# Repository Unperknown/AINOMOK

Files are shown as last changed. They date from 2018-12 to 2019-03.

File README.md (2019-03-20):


HitCount (http://hits.dwyl.io/Unperknown/AINOMOK)

# AINOMOK

📜
**[View Entire Documentation](https://github.com/Unperknown/AINOMOK/blob/master/doc/Plan%20Document.pdf)**

2016년에 성행한 알파고와 이세돌과의 경기 모습에서 영감를 받아 오목을 두는 기계와 사람이 오목 게임을 할 수 있도록 한다. 기계는 인공지능이 내장된 데스크탑과 통신하여 실제 고수와 같이 게임하는 것 같이 구현하였다.

구현을 위한 영상 처리 기술과 인공 지능은 Python 라이브러리 OpenCV와 Tensorflow를 사용해 작성하였으며 기계 제어와 통신 프로세스는 Arduino의 GRBL쉴드를 사용하여 3D Printer와 흡사하게 작동 할 수 있도록 C언어로 작성하였다. 물리적 설계는 3D 모델링으로 Fusion 360을 사용하였다.

## 📊Purpose

우리 학교 특성 상 소프트웨어 개발에 집중되어 있어 실제 기계에서 소프트웨어가 어떻게 활용되는지 알 수 없었는데 이번에 프로젝트를 진행하면서 알고 싶어서 로봇에 인공지능을 넣을 수 있도록 하였다.

그리고 조립한 기계 산출물이 전시회 이후에 사용되지 않고 버려지는 문제점에서 벗어나기 위해 보다 더 실용도가 높은 산출물을 개발하고 싶어서 최대한 흥미로운 아이디어를 접목하고 싶었다.

## ☑️Features
- 로봇은 오목판의 영상 처리를 통해 현재 상태를 분석하여
둘 수 있는 수 중 최적의 수를 전달한다.
- 구성품의 LCD 패널에서 출력되는 정보를 통해 현재 게임 스테이지의 상태를
알 수 있다.

## 🔘Entire Design
### Estimated Outputs
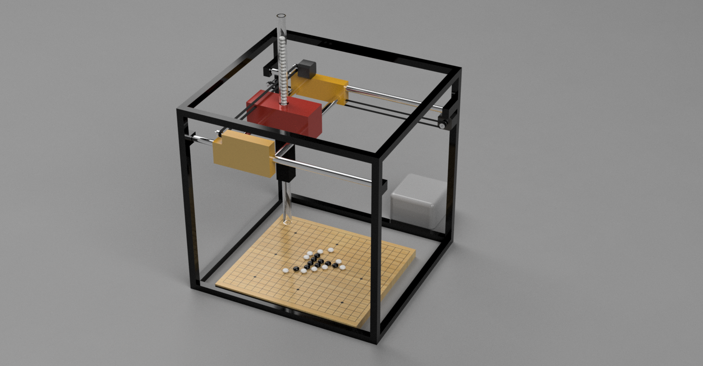
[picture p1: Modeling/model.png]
예상 완성본 모델링 사진


### System Design

## 👪Contributors

### Project Group
- [🔗Unperknown](https://github.com/Unperknown) : Image Processing, AI Development
- [🔗asphalt-alpha](https://github.com/asphalt-alpha) : Assembling Robot, 3D Modeling
- [🔗ohseyoung123](https://github.com/ohseyoung123) : Arduino Programming

### Others
- [🔗Las-Wonho](https://github.com/Las-Wonho) : Correction of document(README.md)
- [🔗cdb0915](https://github.com/cdb0915) : Arduino Programming Assistant

## 🔑Stack
  
- Python
  - Tensorflow(for C: Partically uses Ubuntu OS)
  - OpenCV

- Arduino

- 3D Printing & Modeling

## 🕤Daily Progress
### Day 1(12/27) - 계획서 수정 및 개발 과정 설계

##### 1. 계획서 버전 수정 및 브로슈어 추가

doc 디렉토리의 계획서를 10/24(Ver.1)에서 12/26(Ver.2)로 Commit하였다. 그리고 계획 수립 과정 중 판넬 구성을 하기로 결정함에 따라 브로슈어 원본을 추가하였다.

##### 2. 시스템 설계
**시스템 설계의 도식은 나중에 업데이트될 예정이다.**

구현은 오목 게임의 상태를 저장하고 제어하는 데스크탑과 물리적인 상태 저장과 출력을 담당하는 아두이노 간의 통신으로 이루어질 것이다. 데스크탑은 웹캠과 연결되어 웹캠에서 주어진 오목판의 이미지를 영상 처리하여 오목판을 저장하는 배열의 각 상태를 업데이트한다. 각 업데이트를 Round로 나누어 각 Round마다 데스크탑에 내장된 RL 모델이 컴퓨터가 둘 좌표를 판단하여 그 좌표를 아두이노에 전달한다.

아두이노는 전달한 좌표에 따라 모터를 제어하는 프로시저에 따라 바둑판의 상태에 알맞게 둔다. 아두이노의 LCD 패널에 게임이 진행 중인지, 끝났는지 표시한다. 그리고 버튼을 눌러 게임을 시작하는 신호나 중지하는 신호를 데스크탑으로 보낸다. 반대로 데스크탑은 오목 게임이 끝나는 Round에 게임이 끝났다는 신호를 아두이노로 보낸다.

### Day 2(12/28) - 개발 세팅 및 테스트 설계(단위 테스트)

##### 1. 부품 조달 확인

부품 조달이 지연되어 실전 테스팅은 시현 직전인 1월 5일부터 1월 7일까지 하기로 결정하였다. 부품이 오는 동안 프로세스의 구현과 RL 모델 훈련을 하는 것으로 결정하여 Day 3부터 본격적으로 개발하기로 하였다.

##### 2. 개발 환경 및 테스트

영상 처리: 테스트는 부품이 오지 않아 임시로 노트북의 웹캠으로 대신 테스트할 것이다. 이미지나 영상을 띄웠을 때 검은 돌과 하얀 돌이 어느 좌표에 있는지 CLI에 출력하는 것으로 단위 테스팅할 것이다.

RL 모델: 시간 내에 구현하지 못할 가능성을 방지하기 위해 시초에는 Python의 easyAI 라이브러리로 먼저 구현할 것이다. 그러고 나서 알맞게 리팩토링하여 Tensorflow 라이브러리로 재작성할 것이다.

3D 모델링: 로봇 하드웨어를 구성하는 부품의 구성을 모델링하여 저장소에 커밋하여 보관한다. 그러고 나서 출력하여 부품이 오는 즉시 조립을 시작할 것이다.

### Day 3 ~ Day 5(12/29, 1/2 ~ 1/3) - 개발 수행

##### 1. Unperknown - Image Processing

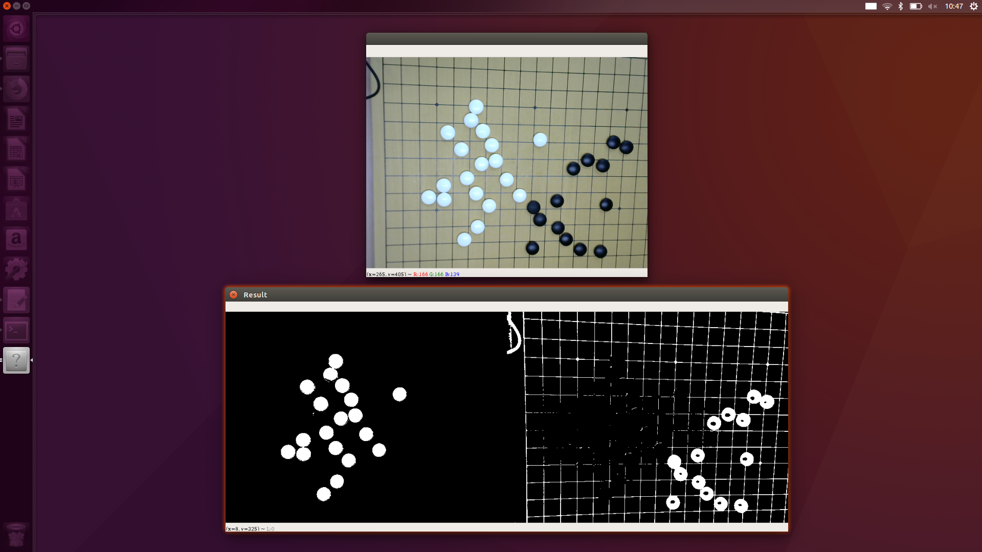
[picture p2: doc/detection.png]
영상 처리를 통한 바둑돌 감지 바둑돌 감지 사진


영상 처리를 통해 임시로 파란색을 감지하는 것을 성공하였다.(12/29) 그러고 나서 지속적인 색 감지 테스트를 통해 검은돌과 하얀돌의 위치를 화면으로 탐지할 수 있게 나는데 성공하였다.(1/3) 그러나 현재 하드웨어가 완성되지 않아 실제로 탐지되는지 테스트를 할 수 없는 상태이다. 색 탐지 값을 조정하는데 하드웨어에 설치된 스탠드의 빛의 밝기, 웹캠의 위치 등에 따라 상당히 달라질 수 있어 좌표의 색을 검출하여 오목판의 상태를 업데이트하는 프로세스는 AI 모델을 완성하고 게임 제어 프로그램을 구성한 후인 가장 마지막에 하기로 결정하였다.

현재 게임 제어 프로그램과 AI 모델은 src 디렉토리를 어떻게 구성할지에 대한 회의가 끝나고 나서 차근차근 커밋할 예정이다.

##### 2. ohseyoung123 - Arduino Programming

시리얼 통신을 C#로 작성하였다. 기본적인 틀을 숙지하고 나서 본격적으로 목적에 알맞게 구현할 것이다. 코드를 짜는데에 어려움을 겪어 검색과 친구들에게 물어봐가며 C++로 작성하려고 하였으나 지속적인 오류가 일어났다.(~1/2)방법을 찾던 중 선배의 도움을 받아 C#으로 작성할 수 있는 방법을 찾아 각 아두이노 핀으로 문자열을 출력하는 데에 성공하였다.(1/3)

##### 3. asphalt-alpha - 3D Modeling

부품을 모델링하였다. 저장소에 커밋하고 나머지 필요한 부품을 추가로 더 할 것이다.

### Day 6 ~ Day 8(1/4 ~ 1/6) - 개발 수행 및 테스트

##### 1. cdb0915 - Assistance of Arduino Programming

시리얼 통신을 구현을 검증하는 중에 ohseyoung123과의 협의를 거쳐 기술 한계 상 Python으로 재작성하자고 결정하였다.(1/4) 그래서 ohseyoung123이 작성한 소스 파일을 리뷰하고 현재 오목 제어 프로그램과 시리얼 통신 프로그램을 합치는 작업을 진행하고 있다.

##### 2. Unperknown - AI Development and Omok Program

하드웨어 안의 오목판의 상태를 담은 데이터를 가져와 현재 Round의 승리 여부를 확인하고 턴을 돌리는 제어 프로그램을 작성하였다.(12/28) 그 제어 프로그램에서 영상 처리를 통해 플레이어가 둔 돌의 좌표를 가져오는 메서드와 AI 모델을 실행하여 좌표를 가져오는 메서드는 현재 작업 중이다. 현재 모델이 훈련이 아직 되지 않았고 생겨난 버그를 수정하고 있다. (1/2 ~) 저번에 언급한 대로 내일(1/6)에 영상 처리를 통해 좌표를 불러오는 메서드를 실제 하드웨어에 연결해 테스트할 예정이다. 그러면서 그 메서드 소스 파일을 커밋할 것이다.

##### 3. asphalt-alpha - Assembling Robot

현재 설계도에 계획한 도면대로 대부분의 물리적 구현을 마치고 있다.(1/4 ~) 그러나 세세한 작업을 하면서 웹캠까지 다 설치하는데 시간이 걸려 최종적인 테스트는 내일(1/7) 하기로 하였다. 

### Day 8 ~ Day 9(1/7 ~ 1/8) - 프로젝트 일시 중단

하드웨어와 프로그램 간의 네트워크 구현이 원활하게 이루어지지 않았고 영상 처리 기술을 구현하는데 시간이 매우 촉박하였다. 그래서 프로토타입만 전시하기로 결정하였다.

### Day 10(5/14? ~ ) - 프로젝트 재개

각 팀원의 스케줄 문제로 2분기 방과후 프로그램에 프로젝트 반을 따로 구성하여 그 시간 동안 완성하기로 결정하였다. 정확한 재개 날짜는 아직 정해지지 않았다.

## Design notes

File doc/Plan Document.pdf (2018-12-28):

## 2018년도 GSM 프로젝트 페스티벌

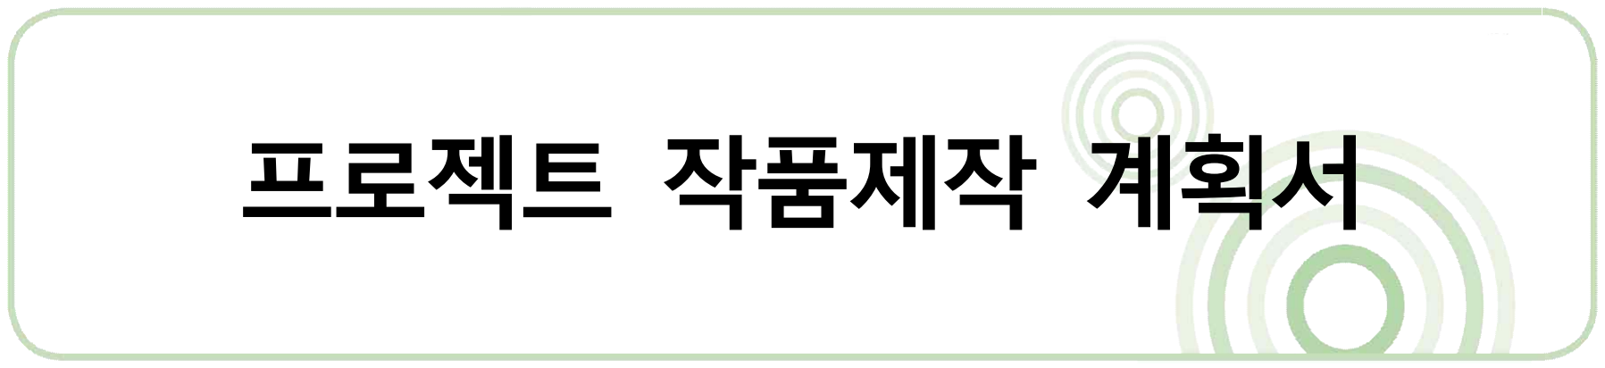
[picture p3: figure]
프로젝트 작품제작 계획서

조명 | New Project
조장 | 1308 | 박건은
조원 | 1408 | 박준영
조원 | 1208 | 오세영

## Ⅰ. 작품 개요

### 1. 프로젝트명 : AINOMOK

### 2. 제작 동기

서로 프로젝트를 계획하면서 각자 배우고 있는 분야가 달라서 그나마 서로 흥미 를 가지고 있었던 인공지능 분야를 선택하였다. 우리 학교 특성 상 소프트웨어 개발에 집중되어 있어 실제 기계에서 소프트웨어가 어떻게 활용되는지 알 수 없 었는데 이번에 프로젝트를 진행하면서 알고 싶어서 로봇에 인공지능을 넣을 수 있도록 하였다. 그러면서 기계와 소프트웨어가 어떻게 주고 받는지 눈여겨보고 싶었다.

### 3. 관련 교과 이론

사람의 지능과 최대한 비슷하게 만드는 인공지능 프로그래밍을 할 것이다. 언어 는 C++, Python으로 작성할 것이며 오목판을 영상으로 인식하는 OpenCV 라이 브러리와 인공지능 개발 도구인 Tensorflow 라이브러리를 사용할 것이다. Ⅱ. 자료 수집 계획

내 용 | 일 정 | 장 소 | 준비물 | 담당 및 점검
Python으로 AI 만들기, 로봇 인터페이스 구축하기 | 11월 4주차 ~ 12월 4주차 | 홈베이스, 랩실 | 인터넷이 연결된 노트북, 관련 서적 | 박준영

오세영

OpenCV 라이브러리
사전 조사, 로봇 구성하기

박건은

## Ⅲ. 준비물 계획

### 1. 예상 완성도

실제 오목판을 두고 사람과 로봇이 오목 대결을 한다. 로봇을 구성하는 인공지능을 쳬계적으로 학습하여 최대한 사람이 이기지 못하도록 완성한다.

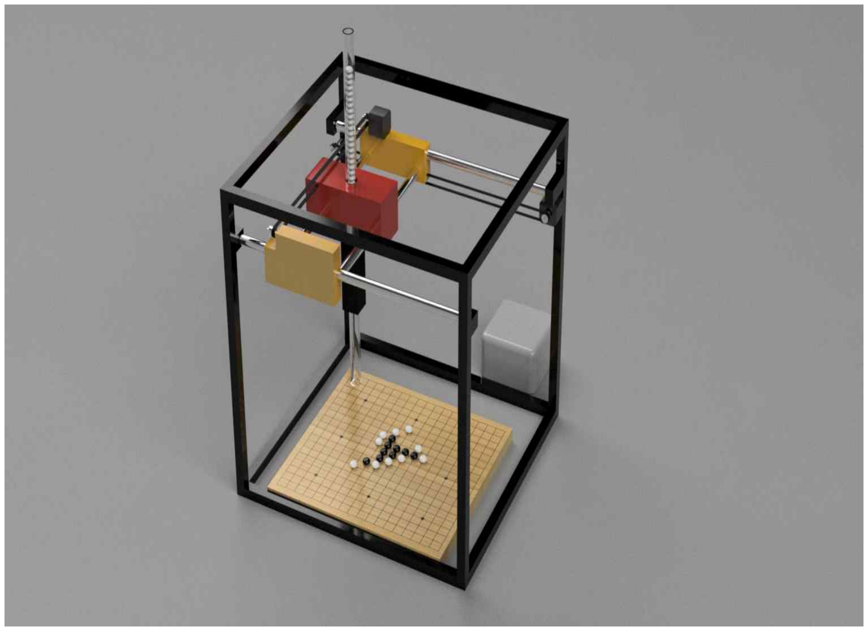
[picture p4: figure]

아두이노에서 전달한 좌표 값에 따라 정육면체 골격에 고정된 축에 달린 서보 모터, 스테핑 모 터를 제어하여 리니어 액추에이터를 작동하여 바둑을 둔다. 골격 위에는 카메라가 달려 있으며 카메라는 실시간으로 영상을 데스크탑에 전송하고 데스크탑에서 영상 처리를 하여 바둑판의 상태 를 업데이트한다. 바둑판의 상태에 따라 데스크탑의 오목 AI가 이길 수 있는 좌표 값을 다시 아 두이노에 전달하여 게임이 마무리될 때까지 반복한다. 오목 게임의 상태는 아두이노에 탑재된 LED의 색으로 구분할 수 있고 스위치를 눌러서 게임을 시작하거나 종료할 수 있다.

### 2. 재료 목록

(자세한 내용은 부록[물품 신청서]에 첨부함)

번 호 | 물 품 이 름 | 용 도
1 | 6형제바둑 바둑알 형제18호P | 실제 오목 게임을 하기 위한 물리적
2 | 경북바둑 25mm 도색 바둑판 장기겸용 | 재료 평판
3 | 아크릴 파이프 25Ø 3T 길이 100cm 압 출 투명 외경 25mm 내경 19mm | 바둑알을 오목 판에 두기 위해
| 아크릴 파이프 26Ø 3T 길이 100cm 압 출 투명 외경 26mm 내경 20mm | 사용하는 관 4
5 | 알루미늄 프로파일 DF2020 | 로봇의 뼈대를 담당하는 철 골격
6 | PLATE BRACKET(20용) | 철 골격이 연결되도록 하는 안정 장치
7 | DCB2025(20용)-실버,블랙
8 | 로지텍)웹켐(C-170) 컴퓨터화상카메라 PC 카메라 | 오목 판의 영상 처리 데이터를 만들어냄
9 | 6V 리니어 서보 액추에이터 L16-R, 50mm (63:1) | 아두이노가 전달한 좌표로 움직인 후, 오목 판과 최대한 가까이 다가갈 수 있도록 해줌
10 | GT2 타이밍 벨트 [열린 타입] | 오목 판의 특정 위치에 도달하도록 연결함
11 | 연마봉 8파이 | 로봇의 각 부품이 오목 판 위에서 직선으로 움직이게 함
12 | 16잇수 풀리/내경5mm | 11번(연마봉)과 모터에 장착하여 10번(타이밍 벨트)를 걸어 11번 위에서 굴러가도록 함
13 | Anet 네마17 모터 [ X축 폴리형 ] | 로봇을 움직이는 모터
14 | Anet 네마17 모터 [ Y축 폴리형 ]
15 | SK8~20 연마봉 고정용 [ SK8 ] | 양쪽 끝에서 11번(연마봉)을 고정함
16 | 모터 브라켓 네마 17용 철 | 모터가 움직이지 않도록 고정함
17 | 캡형 볼부쉬/[3-1] SC 8UU [캡형] | 로봇의 각 부품이 11번(연마봉)에서 굴러갈 수 있도록 함
18 | 모터드라이버 A4988 | 모터를 제어하는 드라이버와 같음
19 | 아두이노 GBRL 호환 CNC 쉴드 [SZH-ET004] | 드라이버와 아두이노를 연결하는 쉴드
20 | SMPS 방수형 12V 60W | 로봇에 전원을 공급하는 장치
21 | CCTV 방수 하이박스, 화이트, [대(大)] | 아두이노를 보관하는 박스

## Ⅳ. 정보기기 활용 계획

### 1. 하드웨어(H/W)

하드웨어명 | 규격 | 수 량 | 용도 | 비 고
노트북 | . | 3 | 로봇 안 소프트웨어 개발, 로봇 테스트 | 각 개인이
| . | 1 | 테스트 결과 저장(사진 촬영) | 소지 중 핸드폰
아두이노 | 53.8 X 68.6mm | 1 | 데스크탑과 통신

### 2. 소프트웨어(S/W)

소프트웨어명 | 규격 | 수 량 | 용도 | 비 고
Visual Studio 2017 | . | 2 | C++ 소스 파일 작성 | 각 개인이
| . | 1 | 소스 파일 작성 | 소지 중 PyCharm

## Ⅴ. 추진 일정 계획

### 1. 월별 일정

단계 일정 | 11월 | 12월
1주 | 2주 | 3주 | 4주 | 5주 | 1주 | 2주 | 3주 | 4주 | 5주

준비 및 주제선정

프로젝트 수행계획

프로젝트 수행

프레젠테이션 콘텐츠 제작

평가 및 전시회

### 2. 역할 분담 계획

담당역할 | 공통 작업 | 세부 개인 작업 | 담당자 | 일정
오목 AI 개발, 로봇과의 통신, 인터페이스 구축, 영상 처리 구현 | 없음 | 오목 규칙 이해, AI 모델 개발, 실제 바둑판 영상 처리 구현, 로봇 인터페이스 구현 | 박준영 | 11월 4주차 ~ 12월 4주차
| 아두이노 모터 제어 프로그래밍 | 컴퓨터와 아두이노(로봇) 시리얼 통신 구현 | 오세영
로봇 제작, 모델링, 영상 처리 전송 | | 영상 처리 전송(좌표), 부품 3D 모델링, 로봇 제작 | 박건은
프리젠테이션 제작 | 발표 내용 구상하기 | 기여한 부분 발표 내용 짜기 발표 대본 구상하기 | 박건은, 박준영, 오세영 | 12월 4주차 ~ 12월 5주차

## Ⅵ. 결론 및 기대효과

### 1. 결론

오목 AI 로봇이 실제 오목판을 보고 직접 다음 수를 예측하고 둘 수 있을 만큼 구현할 것이다. 인공지능 학습을 최대한 고수들의 단계만큼 둘 수 있도록 개발할 것이다. 처음으로 대형 프로젝트에 팀으로 참여하므로 각자 맡은 분야에서 실력 을 키울 수 있을 것이고 서로 협동하고 사람들끼리 팀으로써 어떻게 조화를 이루 는지 경험하게 될 것이다. 자유 주제로 직접 고안해내는 것이기 때문에 이 프로 젝트를 진행하면서 아이디어를 구상하는 과정에서 서로 창의성을 키울 수 있을 것이다.

### 2. 기대 효과

이번 프로젝트를 진행하여 우리 학교의 특색을 담아 인공지능 로봇을 구현함으 로써 실제 실무에서 어떻게 프로젝트를 구상하고 개발하는지 미리 겪어볼 수 있 을 것이다. 그래서 각자 자신의 전공 능력을 키울 수 있고 포트폴리오에 기재하 여 나중에 취업할 때 도움이 될 것으로 예상한다. 프로젝트 자체에서 사람과 로 봇이 직접 오목을 하는 것이기 때문에 시연회가 끝나더라도 나중에 계속 사용할 수 있어 실용도가 높을 것이다. 그리고 인공지능 분야가 요즘 4차 산업혁명 시대 에서 가장 주목받고 있기 때문에 그 자체만으로 관심을 끌 수 있을 것이다. 또, 일반 소규모 프로젝트에서 하지 못한 규모가 크고 어려운 분야이기 때문에 그 분

야에 도전적으로 참여해서 문제를 해결하는 능력을 키울 수 있을 것이다.

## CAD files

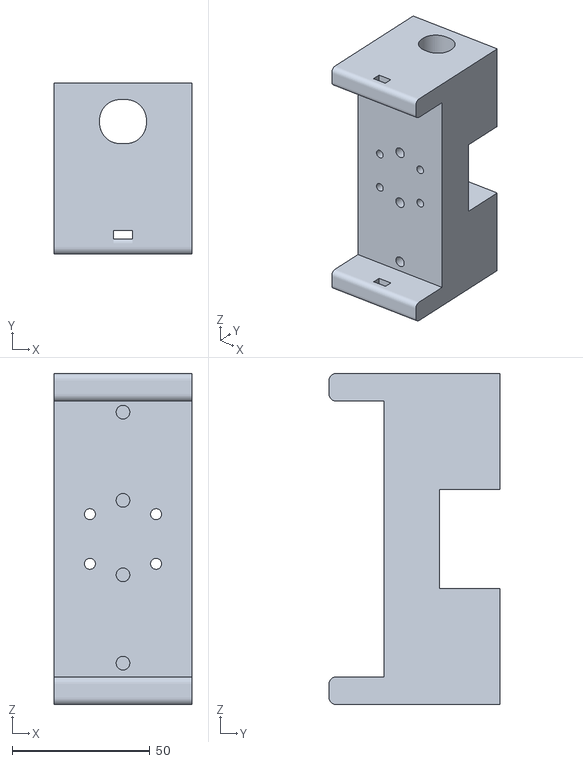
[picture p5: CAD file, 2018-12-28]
Modeling/x_block.stl
50.0 x 62.0 x 120.0

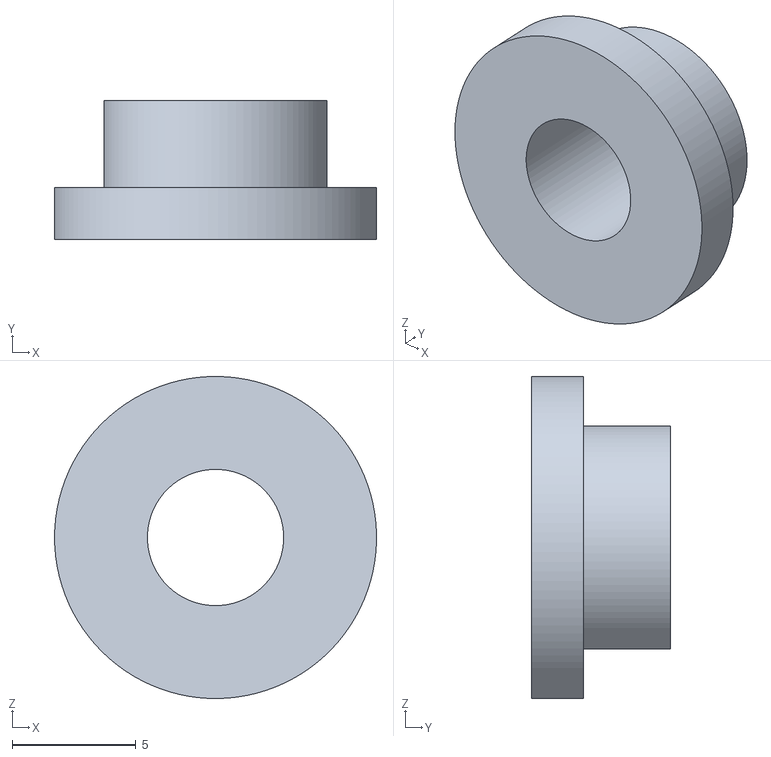
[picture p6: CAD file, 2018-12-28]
Modeling/13-4_poly.stl
13.0 x 5.60 x 13.0

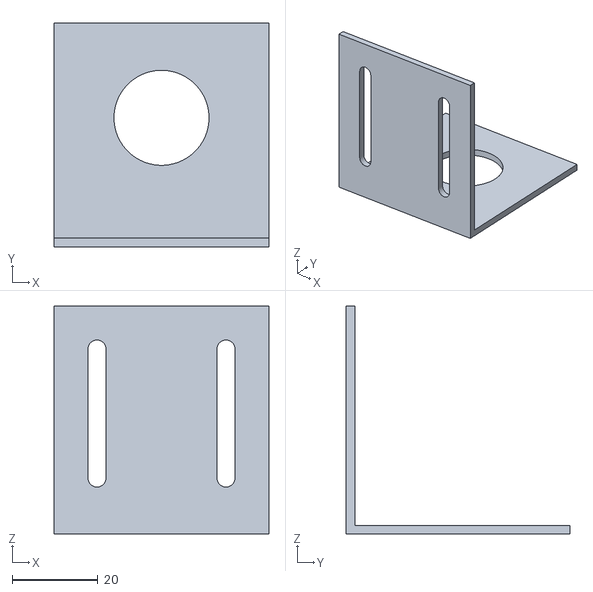
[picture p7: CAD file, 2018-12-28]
Modeling/x_bracket_motor.stl
50.0 x 52.0 x 53.0

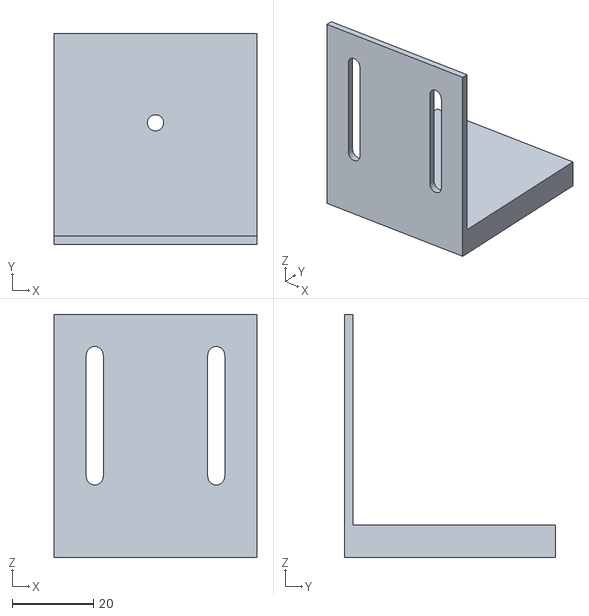
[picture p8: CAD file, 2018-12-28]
Modeling/x_braket_roller.stl
50.0 x 52.0 x 60.0

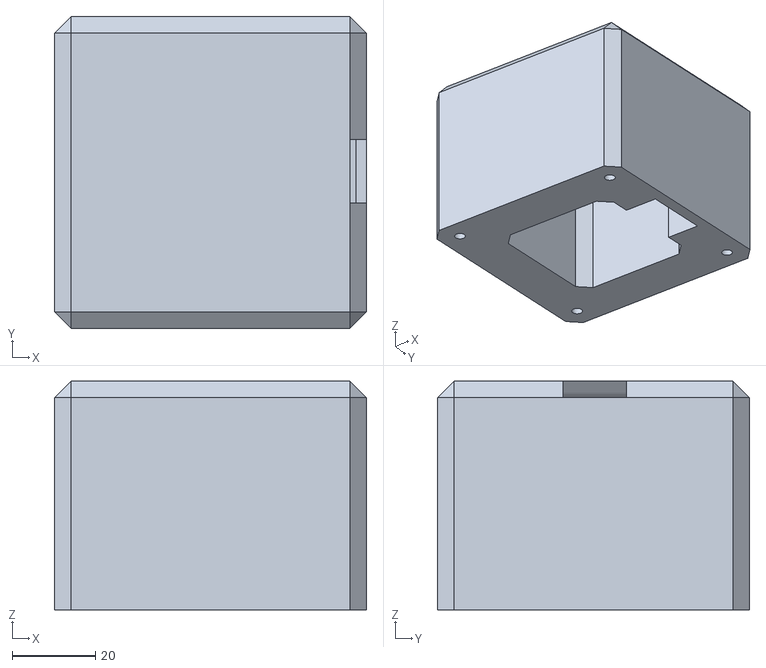
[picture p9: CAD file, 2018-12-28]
Modeling/stepping_motor_cover.stl
75.0 x 75.0 x 55.0

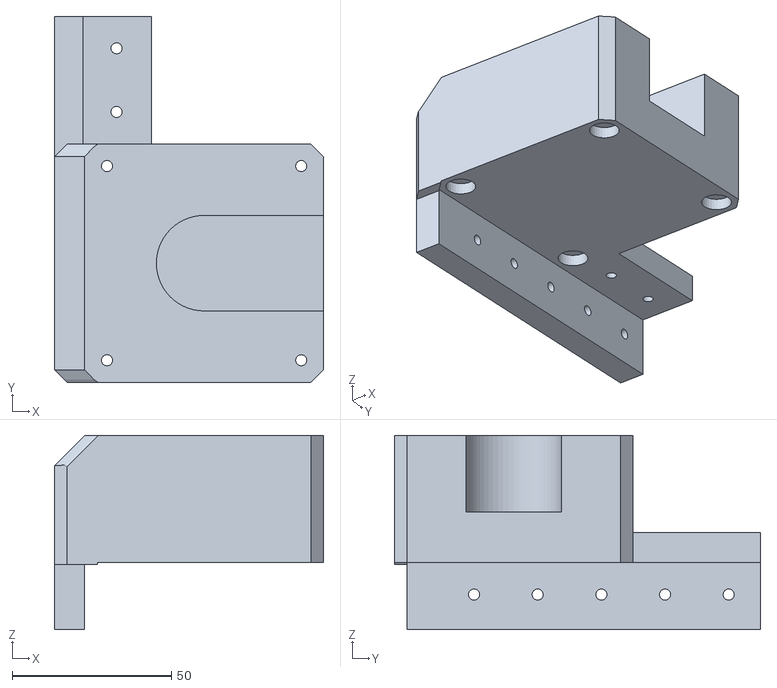
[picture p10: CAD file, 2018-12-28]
Modeling/stepping_motor_bracket.stl
84.5 x 115.0 x 61.0

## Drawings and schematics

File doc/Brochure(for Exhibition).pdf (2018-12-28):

# 2018 GSM 프로젝트 Festival 학년-조 번호

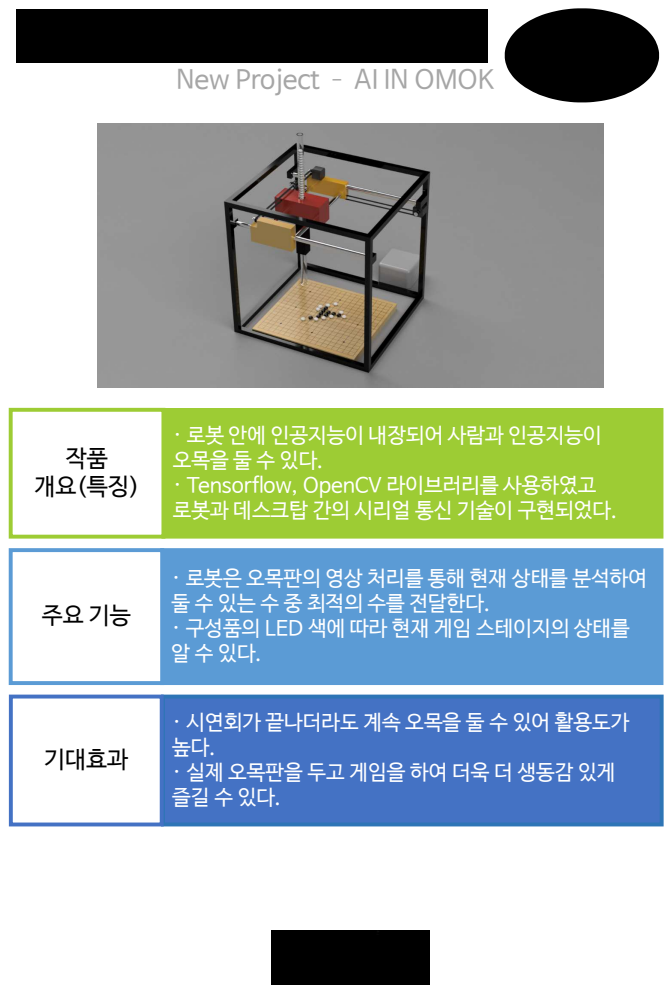
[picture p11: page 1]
기대효과

New Project – AI IN OMOK

· 로봇 안에 인공지능이 내장되어 사람과 인공지능이
오목을 둘 수 있다.
· Tensorflow, OpenCV 라이브러리를 사용하였고
로봇과 데스크탑 간의 시리얼 통신 기술이 구현되었다.

· 로봇은 오목판의 영상 처리를 통해 현재 상태를 분석하여
둘 수 있는 수 중 최적의 수를 전달한다.
· 구성품의 LED 색에 따라 현재 게임 스테이지의 상태를

· 시연회가 끝나더라도 계속 오목을 둘 수 있어 활용도가
· 실제 오목판을 두고 게임을 하여 더욱 더 생동감 있게

## 오세영

## 박건은

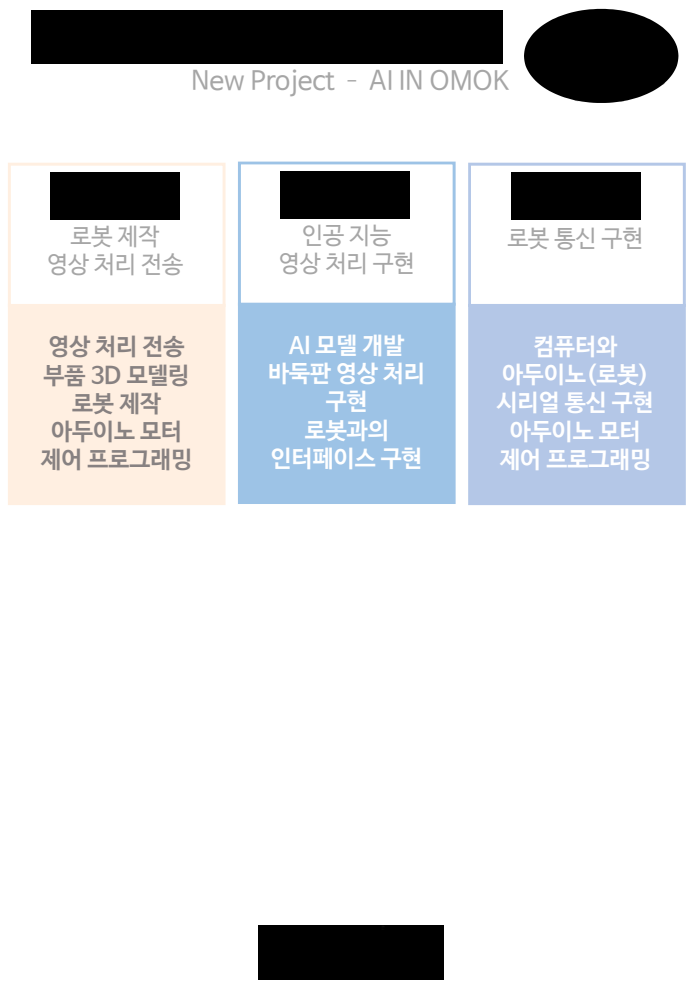
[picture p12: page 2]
2018 GSM 프로젝트 Festival

1-8 New Project – AI IN OMOK

박준영

바둑판 영상 처리
로봇과의
인터페이스 구현

부품 3D 모델링
아두이노 모터
제어 프로그래밍

컴퓨터와
아두이노(로봇)
시리얼 통신 구현

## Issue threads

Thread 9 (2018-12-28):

바둑판 영상처리 반환 데이터 전송 문제

Unperknown, 2018-12-28:
현재 OpenCV Python API로 바둑판 이미지의 각 픽셀의 색 값을 분석하여 검은 돌의 위치와 하얀 돌의 위치를 판별하여 최종적으로 바둑판 상태를 변경하는 프로세스를 구현하고 있습니다.

그런데 웹캠을 설치하는데 데스크탑과의 연결이 잘 되는지 궁금합니다. 만약 그렇지 않으면 이미지를 전송하는 데 필요한 통신을 따로 구현해야 해서 이 부분에 대해서 답변해주시기 바랍니다.

asphalt-alpha, 2018-12-29:
컴퓨터와 웹캠을 usb로 연결할겁니다.

Closed 2019-01-03.

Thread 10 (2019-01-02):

아두이노 프로그래밍 요구사항

asphalt-alpha, 2019-01-02:
프로그램 시작
->아두이노에서  3번핀에 연결된 스위치를 누름
     -> 아두이노에서 C++ 프로젝트로 Serial.Write 명령을 이용하여"start"라는 문자열 전송

 사용자의 턴 일때
-> LCD로 0행에 "Your Turn" 출력. 1행에는 60초의 타이머가 흐르는 것을 출력
-> 만약 50초가 지났다면 LCD 패널 0행에 "Hurry Up!" 출력
-> 만약 60초가 지나거나 스위치가 눌렸다면 LCD 패널 0행에 "com Turn" 출력과
     아두이노에서 C++ 프로젝트로 Serial.Write 명령을 이용하여"over"라는 문자열 전송

 아두이노에서 C++ 프로젝트를 통해 "endp" 라는 문자열을 받았을 때
-> LCD 패널 0행에 "You Win!!" 출력.

 아두이노에서 C++ 프로젝트를 통해 "endc" 라는 문자열을 받았을 때
-> LCD 패널 0행에 "com Win" 출력.

 Round 종료 후
-> LCD 패널 0행에 "Try Again?" 출력

 다시 처음으로

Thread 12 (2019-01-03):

src 디렉토리 구성

Unperknown, 2019-01-03:
앞으로 저번에 계속 작성하고 있었던 소스 파일들을 올리려고 합니다. 그런데 src 디렉토리 안이 현재 이렇게 구성되어 있는데
```
src /
   AINOMOK /
        Arduino /
        Image_Processing /
        Q-Learning Omok /
        x64 /
        나머지 Visual Studio 구동에 필요한 파일들
   AINOMOK.sin -> 솔루션 파일
```
지금 생각해보니 굳이 Visual Studio 라이브러리 구성에 얽매일 필요 없이 Python module로 바꾸는 것이 더 좋을 것 같습니다. 그래서 제가 추천하고자 하는 방식은
```
unittests.py
src /
    Game.py
    Board.py
    Player.py
    Computer.py
    detection /
         detectStone.py
         sendUpdate.py
    ai /
        SSS.py
    arduino /
        ???.cpp
```
이와 같습니다. 이에 대해서 리뷰를 남겨주시고 토의한 방식대로 master branch에 올리도록 하겠습니다. 파일 충돌을 막기 위해 올리고 나면 자신의 branch에 있는 디렉토리를 조정하시기 바랍니다.

asphalt-alpha, 2019-01-03:
파이썬 프로젝트와 아두이노 간의 시리얼 통신도 가능하니 이렇게 진행 하셔도 될 것 같습니다.

Unperknown, 2019-01-03:
바꿀 때 일어날 리스크가 없는 것으로 알겠습니다. ohseyoung123의 의견까지 들은 다음에 위에서 제안한 방식대로 src 디렉토리 구성을 바꾸도록 하겠습니다. 위에서 강조했던 대로 자신의 branch에 업데이트해주시기 바랍니다.

ohseyoung123, 2019-01-03:
동의합니다.

Closed 2019-01-03.

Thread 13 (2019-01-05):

아두이노 제어 프로세스 구성 관련 문제

Unperknown, 2019-01-05:
cdb0915와 협의한 뒤로 아두이노 제어 프로세스를 원래 C++로 작성하려다 Python으로 작성하기로 결정한 사안에 대해서 이야기하도록 하겠습니다.

아직 커밋하지 않은 소스 파일이 남아있지만 어제 긴 협의를 거쳤으므로 Python으로 같이 페어 프로그래밍하는 것이 어려운 작업이 아닐 것으로 예상합니다. 최대한 실전 테스트를 거치는 내일까지 완료해주시기 바랍니다.

asphalt-alpha, 2019-01-05:
현배 하드웨어 구성은 거의 다 끝났으나 lcd패널 제어와 프로그래밍이 많이 진행 되지 않은 상태입니다. 빠른 시일 내에 완료하도록 하겠습니다.

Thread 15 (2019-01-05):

바둑판 크기에관해서...

asphalt-alpha, 2019-01-05:
현재 하드웨어 모터 궝이 완료되었습니다.
완료되어 확인 해 보니 로봇이 바둑돌을 놓을 수 있는 공간이 바둑판의 19x19를 넘지 못 할 수도 이쓸것 같습니다. 혹시 이에 관해서 AI 모델에서 에러 사항이나 문제점이 있다면 확인하여 주십시오

Unperknown, 2019-01-05:
모델이 오목 판 크기에 따라 유동적으로 훈련할 수 있게 설계되어 있으나 한 번 점검을 해보아야 할 것 같습니다. 최대한 정사각형 형태로 될 수 있도록 하는 것이 더 좋을 것 같습니다.

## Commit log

2018-12-27 #1 [ADDED] motor fix
    스테핑 모터를 알루미늄 프로파일에고정시키는 부품 모델링 함
    [stepping_motor_bracket_4.stl, stepping_motor_cover.stl]
2018-12-27 Update README.md
    README파일을 수정하였습니다.
2018-12-28 #2 {DELETE}
    필요없어서 지움
2018-12-28 #2 [DELETE]
    필요가 없어서 지움
2018-12-28 #11 [CHANGE] led -> lcd
2018-12-28 #3 [ADDED] x, y parts
    x축 모터 고정 부품과 x축 과 y축이 연결되는 부품을 모델링 함.
    [13-4_poly.stl, stepping_motor_bracket.stl, x_block.stl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]
2018-12-28 #13 [CHANGED] moved files
    [13-4_poly.stl, stepping_motor_bracket.stl, stepping_motor_cover.stl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]
2018-12-28 #unperknown-1 [ADDED] moved files
    [13-4_poly.stl, stepping_motor_bracket.stl, stepping_motor_cover.stl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]
2019-01-02 #15 [ADDED] Detection on Board
2019-01-03 #25[ADDED]
    ##### 2. ohseyoung123 - Arduino Programming
    시리얼 통신을 C#로 작성하였다. 기본적인 틀을 숙지하고 나서 본격적으로 목적에 알맞게 구현할 것이다. 코드를 짜는데에 어려움을 겪어 검색과 친구들에게 물어봐가며 C++로 작성하려고 하였으나 지속적인 오류가 일어났다.(~1/2)방법을 찾던 중 선배의 도움을 받아 C#으로 작성할 수 있는 방법을 찾아 각 아두이노 핀으로 문자열을 출력하는 데에 성공하였다.(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
2019-01-18 Update Readme.md
    기계적인 프로세스구현이 약간 다른것 같아 수정하였습니다.
